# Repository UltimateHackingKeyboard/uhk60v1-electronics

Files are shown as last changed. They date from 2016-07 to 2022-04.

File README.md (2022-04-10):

Ultimate Hacking Keyboard electronics
=====================================



Contained are the schematics and board layout KiCad files for the [Ultimate Hacking Keyboard](https://ultimatehackingkeyboard.com/).

Please make sure to clone this repo with:

`git clone --recursive https://github.com/UltimateHackingKeyboard/uhk60v1-electronics.git`

Now, you should be able to open any of the 4 [KiCad](https://kicad.org/) projects of the repo:

* [left-main](left-main) contains main PCB of left keyboard half.
* [right-main](right-main) contains the main PCB of the right keyboard half.
* [display](display) contains the PCB that interfaces our custom manufactured LED segment display with the left main PCB.
* [connectors](connectors) are very small PCBs that are soldered vertically to the left and right main circuit boards to interconnect the keyboard halves without needing a bridge cable.

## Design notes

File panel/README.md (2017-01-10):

# Panelization script

Run `generate-panel.sh` to create a `panel.kicad_pcb` file out of every boards of the UHK. Then you shall generate gerbers from `panel.kicad_pcb` and send them to the fab house of your choice.

Please note that `generate-panel.sh` merely places the boards next to each other based on static coordinate offsets and does not add routing, breakout tabs, or anything fancy. This may or may not work out for you.

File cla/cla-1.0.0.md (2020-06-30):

# Contributor Agreement
## Individual Contributor Exclusive License Agreement version 1.0.0

Thank you for your interest in contributing to Ultimate Gadget Laboratories Kft.'s Ultimate Hacking Keyboard electronics design ("We" or "Us").

The purpose of this contributor agreement ("Agreement") is to clarify and document the rights granted by contributors to Us.

By signing this Agreement, you agree that the following terms apply to all of your past, present and future contributions to the project.

## How to use this Contributor Agreement

If You are an employee and have created the Contribution as part of your employment, You need to have Your employer approve this Agreement or sign the Entity version of this document. If You do not own the Copyright in the entire work of authorship, any other author of the Contribution should also sign this – in any event, please contact Us at support@UltimateHackingKeyboard.com

## 1. Definitions

**"You"** means the individual Copyright owner who Submits a Contribution to Us.

**"Contribution"** means any original work of authorship, including any original modifications or additions to an existing work of authorship, Submitted by You to Us, in which You own the Copyright.

**"Copyright"** means all rights protecting works of authorship, including copyright, moral and neighboring rights, as appropriate, for the full term of their existence.

**"Material"** means the software or documentation made available by Us to third parties. When this Agreement covers more than one software project, the Material means the software or documentation to which the Contribution was Submitted. After You Submit the Contribution, it may be included in the Material.

**"Submit"** means any act by which a Contribution is transferred to Us by You by means of tangible or intangible media, including but not limited to electronic mailing lists, source code control systems, and issue tracking systems that are managed by, or on behalf of, Us, but excluding any transfer that is conspicuously marked or otherwise designated in writing by You as "Not a Contribution."

**"Documentation"** means any non-software portion of a Contribution.

## 2. License grant

### 2.1 Copyright license to Us

Subject to the terms and conditions of this Agreement, You hereby grant to Us a worldwide, royalty-free, exclusive, perpetual and irrevocable (except as stated in Section 8.2) license, with the right to transfer an unlimited number of non-exclusive licenses or to grant sublicenses to third parties, under the Copyright covering the Contribution to use the Contribution by all means, including, but not limited to:

* publish the Contribution,
* modify the Contribution,
* prepare derivative works based upon or containing the Contribution and/or to combine the Contribution with other Materials,
* reproduce the Contribution in original or modified form,
* distribute, to make the Contribution available to the public, display and publicly perform the Contribution in original or modified form.

### 2.2 Moral rights

Moral Rights remain unaffected to the extent they are recognized and not waivable by applicable law.

### 2.3 Copyright license back to You

Upon such grant of rights to Us, We immediately grant to You a worldwide, royalty-free, non-exclusive, perpetual and irrevocable license, with the right to transfer an unlimited number of non-exclusive licenses or to grant sublicenses to third parties, under the Copyright covering the Contribution to use the Contribution by all means, including, but not limited to:

* publish the Contribution,
* modify the Contribution,
* prepare derivative works based upon or containing the Contribution and/or to combine the Contribution with other Materials,
* reproduce the Contribution in original or modified form,
* distribute, to make the Contribution available to the public, display and publicly perform the Contribution in original or modified form.

This license back is limited to the Contribution and does not provide any rights to the Material.

## 3. Patents

### 3.1 Patent license

Subject to the terms and conditions of this Agreement You hereby grant to Us and to recipients of Materials distributed by Us a worldwide, royalty-free, non-exclusive, perpetual and irrevocable (except as stated in Section 3.2) patent license, with the right to transfer an unlimited number of non-exclusive licenses or to grant sublicenses to third parties, to make, have made, use, sell, offer for sale, import and otherwise transfer the Contribution and the Contribution in combination with any Material (and portions of such combination). This license applies to all patents owned or controlled by You, whether already acquired or hereafter acquired, that would be infringed by making, having made, using, selling, offering for sale, importing or otherwise transferring of Your Contribution(s) alone or by combination of Your Contribution(s) with any Material.

### 3.2 Revocation of patent license

You reserve the right to revoke the patent license stated in section 3.1 if We make any infringement claim that is targeted at your Contribution and not asserted for a Defensive Purpose. An assertion of claims of the Patents shall be considered for a "Defensive Purpose" if the claims are asserted against an entity that has filed, maintained, threatened, or voluntarily participated in a patent infringement lawsuit against Us or any of Our licensees.

## 4. Disclaimer

THE CONTRIBUTION IS PROVIDED "AS IS". MORE PARTICULARLY, ALL EXPRESS OR IMPLIED WARRANTIES INCLUDING, WITHOUT LIMITATION, ANY IMPLIED WARRANTY OF SATISFACTORY QUALITY, FITNESS FOR A PARTICULAR PURPOSE AND NON-INFRINGEMENT ARE EXPRESSLY DISCLAIMED BY YOU TO US AND BY US TO YOU. TO THE EXTENT THAT ANY SUCH WARRANTIES CANNOT BE DISCLAIMED, SUCH WARRANTY IS LIMITED IN DURATION AND EXTENT TO THE MINIMUM PERIOD AND EXTENT PERMITTED BY LAW.

## 5. Consequential damage waiver

TO THE MAXIMUM EXTENT PERMITTED BY APPLICABLE LAW, IN NO EVENT WILL YOU OR WE BE LIABLE FOR ANY LOSS OF PROFITS, LOSS OF ANTICIPATED SAVINGS, LOSS OF DATA, INDIRECT, SPECIAL, INCIDENTAL, CONSEQUENTIAL AND EXEMPLARY DAMAGES ARISING OUT OF THIS AGREEMENT REGARDLESS OF THE LEGAL OR EQUITABLE THEORY (CONTRACT, TORT OR OTHERWISE) UPON WHICH THE CLAIM IS BASED.

## 6. Approximation of disclaimer and damage waiver

IF THE DISCLAIMER AND DAMAGE WAIVER MENTIONED IN SECTION 4. AND SECTION 5. CANNOT BE GIVEN LEGAL EFFECT UNDER APPLICABLE LOCAL LAW, REVIEWING COURTS SHALL APPLY LOCAL LAW THAT MOST CLOSELY APPROXIMATES AN ABSOLUTE WAIVER OF ALL CIVIL OR CONTRACTUAL LIABILITY IN CONNECTION WITH THE CONTRIBUTION.

## 7. Term

7.1 This Agreement shall come into effect upon Your acceptance of the terms and conditions.

7.2 In the event of a termination of this Agreement Sections 4, 5, 6, 7 and 8 shall survive such termination and shall remain in full force thereafter. For the avoidance of doubt, (sub)licenses that have already been granted for Contributions at the date of the termination shall remain in full force after the termination of this Agreement.

## 8. Miscellaneous

8.1 This Agreement and all disputes, claims, actions, suits or other proceedings arising out of this agreement or relating in any way to it shall be governed by the laws of Hungary excluding its private international law provisions.

8.2 This Agreement sets out the entire agreement between You and Us for Your Contributions to Us and overrides all other agreements or understandings.

8.3 In case of Your death, this agreement shall continue with Your heirs. In case of more than one heir, all heirs must exercise their rights through a commonly authorized person.

8.4 If any provision of this Agreement is found void and unenforceable, such provision will be replaced to the extent possible with a provision that comes closest to the meaning of the original provision and that is enforceable. The terms and conditions set forth in this Agreement shall apply notwithstanding any failure of essential purpose of this Agreement or any limited remedy to the maximum extent possible under law.

8.5 You agree to notify Us of any facts or circumstances of which you become aware that would make this Agreement inaccurate in any respect.

## 9. Signatures

I have read this Agreement, and fully agree to it by signing it with my GitHub username:

- @ipanti
- @mondalaci
- @spuder

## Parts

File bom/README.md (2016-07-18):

# BOM generator

1. Invoke `npm install` to install the dependencies.
2. Generate report files which serve as the input of the script by opening the left-main, right-main, and display board in pcbnew and clicking on File > Fabrication Outputs > Footprint (.rpt) Report.
3. Execute `bom-generator.js`

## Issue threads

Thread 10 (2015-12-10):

Re-wrap and reposition the "Unscrew the 5 large below the keycaps..."

spuder, 2015-12-10:
Re-wrap and reposition the "Unscrew the 5 large below the keycaps and the 1 screw on the PCB" text to be more readable.

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

spuder, 2015-12-10:
@mondalaci Could I get some feedback on what you are looking for here?

Here is one proposal that rephrases for less characters and moves text a little further away from the vias / holes.

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

mondalaci, 2015-12-10:
@spuder Your suggested solution looks great! I'd love to merge a pull request implementing the above.

Closed 2016-01-05.

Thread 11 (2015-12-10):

Move the parts farther from the pins of the MX switches which are too close

spuder, 2015-12-10:

mondalaci, 2016-09-27:
I'll do this along with a number of other related changes. Now we know the exact specs for selective reflow soldering.

Closed 2016-09-27.

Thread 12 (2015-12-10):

Use larger pitch components?

spuder, 2015-12-10:
Look into the possiblity of using larger pitch components so that we could could make our manufacturing tolerances less strict resulting in lower prices and increased yield

mondalaci, 2016-09-27:
Now we use the largest pitch components possible.

Closed 2016-09-27.

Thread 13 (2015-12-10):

Add fixating pins to the Cherry MX module

spuder, 2015-12-10:
Add fixating pins to the Cherry MX module so that PCB mounted switches can be used, too

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

There are two libraries that already have this

https://github.com/geekhack-org/kicad-library

https://github.com/c0z3n/cherrymx-eagle

The latter would need to be converted to kicad. (done)

- [x] Ensure license is compatible with the UHK https://github.com/geekhack-org/kicad-library/issues/1
- [x] Get cherry mx library https://github.com/UltimateHackingKeyboard/ugl-kicad-libs/pull/2

mondalaci, 2016-09-27:
Done.

Closed 2016-09-27.

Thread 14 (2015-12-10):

Add pins for Matias switches if possible

spuder, 2015-12-10:
Not impossible, but difficult
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

mondalaci, 2015-12-13:
I've seen two examples of implementing this. I assume that the double hole version probably works better, but maybe we should ask Matias.

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

spuder, 2016-01-04:
I've contacted Matias support a couple of times with no response, asking if they have cad files. I haven't been able to find any github projects that contains a matias libraries, though this one looks promising.

https://github.com/kiibohd/pcb/tree/master/ICED%20-%20Right/prettylib

spuder, 2016-01-05:
Matias switch cad files can be downloaded from here:

http://matias.ca/switches/Matias_Switch_3D.zip

They are in the format .EPRT .IGS and .STEP They will need to be converted to a .kicad_mod file

Here are the blueprints:

Quiet Click
http://matias.ca/switches/quiet/blueprints/?p=4

Click
http://matias.ca/switches/click/blueprints/?p=1

Quiet Linear
http://matias.ca/switches/linear/blueprints/?p=1

mondalaci, 2016-01-05:
Great job! Looks like all of the above information is indirectly accessible via http://matias.ca/switches/

Just emailed Matias and asked them about the suggested universal switch footprint along with some further info.

spuder, 2016-01-07:
I spent some time creating a custom part from the blueprints, only to later find that the buttons library included in kicad already includes a matias part!

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

spuder, 2016-01-12:
This has been completed for the left hand side.
https://github.com/spuder/electronics/tree/feature/%2313_matias
 It has the following considerations that need to be reviewed

- 4 new vias near iso switches are different from the via part that is in the ugl library. I don't see a way to change the built in via into a ugl:via

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
- Switch 27 has a hole that goes off the end of the board. Will that cause a problem?

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

The following are items that shouldn't cause problems, but should be closely inspected

- verify that there is enough space for the vertical capacitor

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

- verify the new layout of capacitors has enough room

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

Lastly, because of the new switch layout that includes the stabilizing holes for the cherry mx boards, there is a DRC that fails. There is no way around this. We could:
1. Allow the DRC to fail for the overlapping pads
2. Create a new custom part that includes strangely shaped holes

Neither solution is ideal. There has been some discussion in the kicad forms on how to handle this situation.

https://forum.kicad.info/t/multiple-pin-components/2006

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

spuder, 2016-01-13:
I spoke with matias. They don't offer any sample kits, but they will sell me 3 keys (one of each type) for $10. Otherwise we would need to buy a 200 key set for $50 (plus another $50 for the keycaps).

http://matias.ca/order/#switches

mondalaci, 2016-01-13:
Sorry for the late reply, these have been busy days.

The most important thing is that the Cherry switches should probably be reversed for optimized backlighting. The reason is that unlike most keyboards the UHK makes heavy use of the front side of the keycaps for featuring the labels of the Mod layer. Because of this, the front labels should be lit. This needs the LEDs to be featured on the user-facing sides of the switches, not the other way.

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

Above is the KBT Pure 60% keyboard to illustrate my point.

In light (no pun intended) of the above, what route would you take, Spencer? I'd rather vote for reversing the switches which would negate some or all of your work. I'd hate to do that but I think it'd make sense to future-proof the design in this respect.

Please let me answer your other questions too a little bit later.

spuder, 2016-01-14:
I agree reversing the part would be best. Doing so would be a very big change and I don't know how soon the board is to being finalized and delivered. I won't be sad if we don't use the work I've done so far because it has been a learning experience. I've used eagle, but never kicad.

Two approaches

## Iterative
Keep working on the board in phases. Ship the version that is ready at the final date.

6.0 => matias + cherry mx stabilizer
7.0 => reversed switches
8.0 => led lights (with reversed switches).

## Incremental
Overhaul board to have all the desired features

reversed switches + matias + cherry mx stabilizer + led lights

---
It all comes down to timing. I estimate the latter would require changing over 30% of the board layout, and would take several months plus new prototypes. If you think there is time, I'm willing to help either way.

spuder, 2016-01-14:
@mondalaci I've been thinking about this more.

I'm ok to throw away the work that I've done on the matias switches, though I think it still might be useful because while adding the cherry mx stabilizer holes, I've moved traces and components out of the way. Rotating the part 180 degrees will reuse those holes.

Here is what I think is the best course of action

To the master branch:
- Add the new pogo plugs
- Swap the atmega for the teensy
- Add the 4P4C

Then try and merge my matias branch. If the merge works, we just need to rotate the components. If the merge doesn't work, then I'm ok to start over. I'm much faster at kicad now.

I suspect this would take a few weeks. Once that is done:

If sufficient time, add the led circuitry
If approaching deadline, skip the leds and get a prototype made.

Thoughts?

spuder, 2016-01-15:
There is a major obstacle to rotating the keycaps around

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

switch 13 might need to be rotated 90 degrees, or left upside down not sure if that would make the led lighting look weird.

mondalaci, 2016-01-15:
This one shouldn't be a problem. Just talked to Andras and he said that the FFC connector can be moved a little farther away from SW13. Relative to SW13 the new position of the FFC connector should be x-4.364mm and y-11.257mm.

mondalaci, 2016-01-15:
Thanks for elaborating on the two approaches, good thinking! I'd rather prefer your incremental approach (reversed switches + matias + cherry mx stabilizer + led lights).

But before executing this complex change it'd be worth to wait for Andras to overhaul the soft keepout areas and slighly tweak the shape of the PCB based on the updated CAD data. He should be ready on the upcoming week, and after that this sweeping change could take place.

At this point I'm only unsure about how to implement LED backlighting for Matias switches. Unlike for Cherry switches this is rather nontrivial but the above overhaul shouldn't be affected by adding Matias LEDs later on.

mondalaci, 2016-01-15:
Regarding the overlapping stabilizer pins of the Cherry switches I think the best solution is to create two additional hybrid footprints that are the same as the hybrid footprint except without left / right stabilizer pins. We could use one of these modified footprints wherever necessary.

mondalaci, 2016-01-15:
Thanks for looking into Matias keycaps, Spencer! I'm not terribly worried about them right now. I'm rather concerned about future-proofing the PCB to make it compatible with Matias switches. We should be able to scavenge most (if not all) of the Matias keycaps from existing Matias/ALPS keyboards that can be purchased from eBay for example.

spuder, 2016-01-18:
For reference, the ergodox infinity was recently updated to support all major keycaps

https://www.massdrop.com/buy/infinity-ergodox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(Active

- Cherry
- Matias
- Gateron
- Zealios

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

It also has usb3 support

mondalaci, 2016-01-18:
Good find!

I can't see how Gateron differs from Cherry. I think Gateron simply has a single version featuring fixation pins. Is Zealios different from the Cherry? I don't think so. It's nice that Matias is supported but elongated holes might be problematic for soldering purposes.

mondalaci, 2016-01-18:
Please let me answer the rest of your questions, Spencer.

It shouldn't be a problem that switch 27 has a hole that goes off the end of the board. Worst case scenario: the stabilizer pin in question will be cut off. But Andras will try to make space for the stabilizer pin in the case.

The vias in question can't be changed to ugl:via because these vias aren't separate modules. You can simply choose the desired via from the via combobox that is located rightwards of the track width combobox below the top menu and then right-click on the via, select it from the pop-up menu, then click on the Change Via Size and Drill menu item.

I think there should be enough space for the vertical capacitor.

When you said "verify the new layout of capacitors has enough room" did you mean resistors? I assume you meant the R22 and its close friends. We'll end up using a resistor network instead of the individual resistors so as long as the DRC is ok the current layout it should be fine.

spuder, 2016-01-21:
For reference, it looks like the corsair k70 uses upside down cherry mx leds. The keycaps also have the transparent letters near the top

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

mondalaci, 2016-01-21:
Almost every keyboard on the market uses upside LEDs. Downside LEDs only make sense when the letters are not only top-printed but side-printed, too.

spuder, 2016-01-25:
@mondalaci I see you added a git submodule for the kibohd footprints.

I've looked into using their footprint instead of the one I made.

https://github.com/kiibohd/pcb/issues/3

Thoughts on using their footprint?

Pros:

- Tested

Cons:

- Matias switch holes are slightly different from matias blueprints
- Can PCB manufacture drill oblong shaped holes?
- Is CERN license compatible with UHK license?
- PCB will 'look' kind of like the ergodox with the oblong holes

If you don't have a problem with these, then I suggest we just use their footprint instead of the one I made.

mondalaci, 2016-01-25:
@spuder I'd prefer to use your version mainly because it should be easier to solder due to the circular drill holes. I've only added the kiibohd repo because it may be worth to use their Kinetis processor module.

I didn't think that license incompatibility may be an isssue. The way I though about it is that these are two separate projects. Would it be problematic to use a CERN-licensed component in a GPL-licensed project?

mondalaci, 2016-09-27:
Done.

Closed 2016-09-27.

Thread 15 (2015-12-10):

Cherry MX LED lights

spuder, 2015-12-10:
Allow modders to use cherry mx switches with LEDs

- [x] Update library to use cherry mx pinout with led holes. [example](http://cherrycorp.com/wp-content/uploads/2014/12/11.gif)   done: https://github.com/UltimateHackingKeyboard/ugl-kicad-libs/pull/2
- [ ] Choose a led driver that handles PWM
- [ ] Determine if sufficient pins available on the AtMega for led driver
- [ ] Design charlieplexing matrix

Optional features

- [ ] Software defined brightness, [like code keyboard https://codekeyboards.com/])
- [ ] Individually toggle buttons (caps lock, num lock)

Related https://github.com/UltimateHackingKeyboard/electronics/issues/13

mondalaci, 2016-01-05:
It'd be useful to take a look at some open source keyboard designs that have backlighting. I'd rather go for a simple implementation that supports a single PWM channel for all the LEDs. So I mean no per-LED backlighting.

spuder, 2016-01-18:
Some possible led drivers

[74HC595 Shift Register](https://www.adafruit.com/products/450)
- only needs 3 pins (SPI)
- can daisy chain
- Have to do charlie plexing in software

[MAX7219 Led Driver](https://www.adafruit.com/products/453)
- Handles control and refreshing. Greatly simplifies code
- Kind of expensive.

I'm leaning towards the first option because it is cheaper.

The teensy has an spi library https://www.pjrc.com/teensy/td_libs_SPI.html

mondalaci, 2016-01-19:
I'm aware of these options. Unfortunately, the 74HC595 only allows for a single LED per pin and the MAX7219 is fabulously expensive.

I've been suggested the TPS61193 lately which may work for us. We could string about a dozen of LEDs per OUTx pin.

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

I personally don't feel confident in my abilities to choose the best part for this purpose and will surely talk to an electronics engineer before making a choice. But suggestions are always welcome!

spuder, 2016-01-19:
Looking at the [ergodox infinity](https://github.com/kiibohd/pcb/tree/master/ICED%20-%20Left), they are using the  [IS31FL3731C](http://www.mouser.com/ProductDetail/ISSI/IS31FL3731C-SALS2/?qs=rnuWwpjhhVvfjmOe6D9bPQ%3D%3D)

mondalaci, 2016-01-19:
Yes, I know, but [nobody has it on stock](https://octopart.com/search?q=IS31FL3731C) which is not very promising.

mondalaci, 2016-02-09:
Apparently, this IC is [actually available](https://octopart.com/search?q=IS31FL3731) without the closing C in its part name.

mondalaci, 2016-09-27:
Done. We went with the IS31FL3731-SALS2.

Closed 2016-09-27.

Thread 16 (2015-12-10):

USB type C connector?

spuder, 2015-12-10:
Look into the possibility of using a USB type C connector

mondalaci, 2016-01-04:
András has looked into the possibility of using USB type-C and concluded that it doesn't fit into the case given its larger size. We'll stick to USB Mini-B. I think it's the best choice given its small size and robust design.

Closed 2016-01-04.

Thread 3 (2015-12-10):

Replace 6P4C connectors with 4P4C

spuder, 2015-12-10:
Replace 6P4C connectors with 4P4C. Make sure that the chosen connector and the wall of the case leaves enough space for the clip so that it can be pressed. Also, 4P4C probably almost always uses reverse wiring!

mondalaci, 2015-12-13:
@spuder Thanks for confirming reverse wiring! I meant to use reverse wiring for 4P4C instead of the current straight wiring because according to my experience telephone cord cables use reverse wiring.

I'd love to back up the prevalence of reverse wiring with facts beyond my (very limited experience) but couldn't find any stats of the percentage of telephone cords with straight vs reverse wiring. The type of wiring shouldn't matter for telephones but it does matter for the UHK.

Andras always does mechanical interference checks in CAD so that shouldn't be an issue.

spuder, 2015-12-13:
Sorry, I can't confirm the reverse wiring as I don't know anything about that part. The comment was copied and pasted directly from the TODO

>-* Replace 6P4C connectors with 4P4C. Make sure that the chosen connector and the wall of the case leaves enough space for the clip so that it can be pressed. Also, 4P4C probably almost always uses reverse wiring!

https://github.com/UltimateHackingKeyboard/electronics/commit/c4327e8296f0e911c573165dafe6d01c02b7f867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

mondalaci, 2015-12-13:
So I commented my own comment - that's hilarious! :)

Sorry, it's my bad, and will look into it another time.

mondalaci, 2016-09-27:
Done.

Closed 2016-09-27.

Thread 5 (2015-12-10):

Replace the spring connector with a vertical PCB that uses pogo pins

spuder, 2015-12-10:

mondalaci, 2016-09-27:
Done.

Closed 2016-09-27.

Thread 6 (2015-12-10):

Reduce resistor values on the TX and RX lines

spuder, 2015-12-10:
Reduce resistor values on the TX and RX lines of the board-to-board connectors because they didn't work on the 5.1 generation prototypes

spuder, 2015-12-13:
R7 => 10K
R8 => 10K
R9 => 100K
R10 => 10K

What values should these be?

mondalaci, 2015-12-13:
Great question! I'm fairly clueless about analog electronics so a professional electronics engineer will revise the design before manufacturing and fix such issues.

In any case, I should add detailed instructions about using the UGL and Opendous KiCad libraries because they're not added by default, which can be seen on the attached picture.

spuder, 2015-12-13:
I was just asking about those libraries in #22

mondalaci, 2016-09-27:
This has been redesigned.

Closed 2016-09-27.

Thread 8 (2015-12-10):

Move via farther from the pad of CR6 on the left main PCB

spuder, 2015-12-10:
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

mondalaci, 2016-09-27:
Not relevant anymore. Individual ESD suppressors have been replaced with ESD suppressor arrays. These kinds of issues will be resolved regardless.

Closed 2016-09-27.

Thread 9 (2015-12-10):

Redesign the pads of the vertical PCB to not interfere with the keycap stabilizer

spuder, 2015-12-10:
Redesign the pads of the vertical PCB to not interfere with the keycap stabilizer. Mechanical solder pads should only be added at the edges and the middle pads should be reduced

mondalaci, 2016-09-27:
Done.

Closed 2016-09-27.

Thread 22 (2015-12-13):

Where do you get the libraries from?

spuder, 2015-12-13:
I know you are really busy, so I'll try and be as self sufficient as possible.

I'm updating the readme with instructions so others can easily contribute. There are 3 libraries required

- special
- opendous
- uhk libs

I've figured out how to install opendous and the uhk libs, but even after a couple hours of searching, I can't find the 'special' library

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

Do you know where that library is located? Once I find it I'll document it so others can find it.

mondalaci, 2015-12-13:
* The "uhk libs" library can be found at https://github.com/UltimateHackingKeyboard/ugl-kicad-libs
* I think this is the relevant Opendous library but please let me know if it doesn't work: https://code.google.com/p/opendous/downloads/detail?name=KiCad_Libraries-2012-10-18.zip&can=2&q=
* I'm not sure about the special library. The "kicad special library" google search yielded https://forum.kicad.info/t/the-following-libraries-were-not-found-special-solved/870 which might be a KiCad bug. Could you please look into it some more?

Thank you so much!

Closed 2015-12-14.

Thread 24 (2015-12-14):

Create automated system to compare kicad diffs

spuder, 2015-12-14:
When a new merge request is made. Use travis-ci to generate gerbers/pdf/png files and then use `linux compare` to generate a visual diff.

http://www.evilmadscientist.com/2011/improving-open-source-hardware-visual-diffs/

https://github.com/blairbonnett-mirrors/kicad/blob/master/demos/python_scripts_examples/plot_board.py

- [x] Create travis config file
- [x] Create scripts to generate diffs based off of plot_board.py
- [x] Create aws account to upload artifacts to s3

You can assign this to me as I'm currently working on it.

mondalaci, 2015-12-14:
Awesome thought of automating this!

Just made you a collaborator of this repo with write access, and assigned this issue to you.
Please let's not change the board files until the visual diff mechanism is in place. I'm very afraid of the board changes as I can't see them and they may result in broken boards which translate to huge problems / losses upon manufacturing the PCB.

Sorry for the delay regarding the other issues, I'll catch up later on.

Thank you so much!

spuder, 2015-12-14:
Awesome thanks.
I understand that you have plenty of other things to worry about right now.
I have some manual diffs ready now, but I'm ok waiting to merge them until we have a more polished diff system in place.

spuder, 2015-12-16:
I have a working implementation in this branch in my fork

https://github.com/spuder/electronics/tree/feature/wip_travis

It still has the following issues:

- Granting public access to the s3
- Minor updates to the diffs
- Decide if travis should generate gerbers too

timofonic, 2015-12-19:
Are there a possibility of making this KiCad native? It would be a great addition for KiCad users!

It would be great if someone implements Git support into KiCad, then auto-generate visual-diffs...

I would like to "hack" your schematics. Your project seems interesting and I would like to donate something, but I'm unable to spend so much money so maybe I can contribute in possible hardware updates or forks :dancer:

spuder, 2015-12-19:
Stand by, i'll be pushing a script soon that uses vagrant and the kicad python api to make images showing diffs. Its as native as can be right now

spuder, 2015-12-21:
I have opened merge request #27 It has a fairly polished collection of scripts that when run generate 14 pdf files, converts them to .png files, and then runs `compare` to show the changes

    ./scripts/generate-png-diff.sh

The script that generates the plots is located externally here:

https://gist.github.com/spuder/4a76e42f058ef7b467d9

It still could use some minor improvements, but it is good enough to see at a glance exactly what was changed.

It also has a travis config file, that runs these scripts.

Here is what happens if nothing has changed:

https://travis-ci.org/spuder/electronics/builds/98057604

Here is what it looks like when a change is made to a file ending in .kicad_pcb

https://travis-ci.org/spuder/electronics/builds/97929762

There are still two remaining tasks

- Automatically upload the .png artifacts to amazon s3 or imgur.com on commit
- Have travis-ci post a link to the generated files inside the comments section of github.

I'll keep working on those, but I want to merge what I have now so that people can use these scripts without waiting.

Here are some samples of what happens when the kicad_file is edited. Here I intentionally moved the rj11 connector:

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

mondalaci, 2015-12-21:
I'm absolutely thrilled about this, thank you so much @spuder! Let me merge the relevant pull request real quick.

mondalaci, 2015-12-21:
@timofonic Sure thing, everybody's welcome to hack the schematic! Let me know if you need any help.

spuder, 2015-12-23:
Marking as done.
Having travis upload the .png files to imgur and automatically posting links in the github comments wont have much use, since travis secrets are not persisted across forks. I won't automate that unless I there is a real need, and I figure out a way that works with forks.

I'll update the README instructing users to upload their diffs manually.

mondalaci, 2015-12-27:
@spuder Thank you for your hard work, this looks excellent the way it is! The rest is only icing on the cake and certainly not urgent.

hoijui, 2020-09-09:
As an alternative, you might want to have a look at the very powerful [KiBot](https://github.com/INTI-CMNB/KiBot) tool.

Closed 2015-12-23.

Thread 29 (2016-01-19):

Parts need unique names to allow for auto routing

spuder, 2016-01-19:
If you attempt to run the auto router, you will get the following errors

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

The first is caused because the holes do not have unique values

The latter is because every via has the same value

mondalaci, 2016-01-19:
I wasn't aware of this issue but I'm not concerned about it because the autorouter is practically useless for complicated designs like the UHK.

I rather wouldn't care about these issues because it would require us to individually name the reference designators of holes and vias which would result in increased mainteance burden on the long run for no real benefit.

Closed 2016-01-19.

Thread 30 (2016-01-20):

Want to add the opensource logo to the board?

spuder, 2016-01-20:
Thoughts on adding the official open source logo to the silkscreen of pcb?

http://www.oshwa.org/definition/

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

https://www.youtube.com/watch?v=QrHoowPpdQ8

mondalaci, 2016-01-20:
Correct me if I'm wrong but I think the UHK is not fully open according to OSH principles because we haven't yet released the CAD files.

spuder, 2016-01-20:
Good point, didn't think of that.

I've read it a few times, and I see how it could be argued both ways. As a whole, the keyboard doesn't meet the criteria yet. The pcb most likely does. I don't know if the enclosure counts.

>The program must include source code, and must allow distribution in source code as well as compiled form. Where some form of a product is not distributed with source code, there must be a well-publicized means of obtaining the source code for no more than a reasonable reproduction cost preferably, downloading via the Internet without charge.

I'll check with the mailing list to get clarification on this principle. I don't think I'll pursue this much further.

Closed 2016-01-20.

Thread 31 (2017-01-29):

Replace 5 pin TVS array footprints with 6 pin footprints

mondalaci, 2017-01-29:
6 pin TVS arrays (SC-74, SOT-223-6, 6-TSSOP) are much more prevalent than 5 pin TVS arrays (SC-74A, SOT-223-5), and they're backwards compatible with 5 pin footprints, so this will enable us to choose a wider variety of parts.

mondalaci, 2017-01-31:
I left a DRC error but I don't care because it's not critical, and the right board is about to be redesigned very soon.

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

Closed 2017-01-31.

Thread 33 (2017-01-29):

Reverse 4P4C connector pins

mondalaci, 2017-01-29:
Currently, the wiring of the bridge cable is backwards, so we should reverse the wiring of either the left or right 4P4C connector.

Closed 2017-02-18.

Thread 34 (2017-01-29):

Create 4 layer versions of the left and right PCBs

mondalaci, 2017-01-29:
Hopefully, #32 will resolve the EMC issues, and we'll pass the next EMC test with flying colors, but we can't be sure. At this point, we want to put the UHK to market as soon as possible, so as a safety measure, we will design 4 layer versions of the left and right PCBs. On the upcoming EMC test, we'll give a whirl to both versions and pick the 4 layer version if necessary.

After finalizing the left and right boards, the `left-main` directory should be copied as `left-main-4-layers` and `right-main` as `right-main-4-layers`, then the 4 layer versions should be redesigned accordingly. The middle layers should exclusively contain GND and VCC.

mondalaci, 2017-02-27:
This has been done.

Closed 2017-02-27.

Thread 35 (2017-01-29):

Protect against reverse polarity bridge cables

mondalaci, 2017-01-29:
Creating custom bridge cables is a possibility, and it's easy to overlook the wiring resulting in reverse-wired bridge cables that can damage the electronics. In order to avoid possible damages, we'll implement reverse voltage protection using the following schematic:

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

The above circuit should be added right between FB1 and C6 according to the following schematic:

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

Closed 2017-01-30.

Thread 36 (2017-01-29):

Add more vias to the female connector board

mondalaci, 2017-01-29:
Currently, there is only one via per pad on the female connector board. We should use more, especially for VCC and GND.

Closed 2017-01-29.

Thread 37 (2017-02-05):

Change MKL03Z8VFK4 to MKL03Z32VFK4

mondalaci, 2017-02-05:
We'll be using the MKL03Z32VFK4 MCU instead of the current MKL03Z8VFK4. It's the exact same MCU in every respect but it has 32K flash instead of 8K. A new schematic part should be cloned from the old MCU accordingly, so its name would reflect the name of the new MCU. The new schematic part will have to be added to the ugl-kicad-lib repo.

Closed 2017-04-16.

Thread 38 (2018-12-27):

Travis script throwing error

zen, 2018-12-27:
I'm trying to use the travis diff script and it's throwing error:
root@12ba8a8b9dbe:/kicad# ./generate-png-diff.sh
Copying 187bd8e:drone-kicad-sample.kicad_pcb to ./plot/187bd8e/
Kicad files saved to:  './plot/current' and './plot/187bd8e'
Converting ./plot/current/drone-kicad-sample.kicad_pcb to .pdf:  Files will be saved to /tmp/pdf
Traceback (most recent call last):
  File "/tmp/plot_board.py", line 172, in <module>
    popt.SetColor(YELLOW)
NameError: name 'YELLOW' is not defined
Converting ./plot/187bd8e/drone-kicad-sample.kicad_pcb to .pdf's Files will be saved to /tmp/pdf
Traceback (most recent call last):
  File "/tmp/plot_board.py", line 172, in <module>
    popt.SetColor(YELLOW)
NameError: name 'YELLOW' is not defined

zen, 2018-12-27:
@spuder probably something for you to take a look.

spuder, 2018-12-27:
Most likely what is going on is an incompatible version of a package that is installed. The travis scripts are only tested on ubuntu 14.04 (trusty).

Are you running these scripts on your workstation? Or is it travis that is failing?

Do you have docker installed? Could you try running these commands and see if it gives the same error?

```
docker run -it --rm -v $(pwd):/data ubuntu:xenial /bin/bash
apt-get update
apt-get install -y sudo software-properties-common
cd /data
./scripts/1-add-repos.sh
./scripts/2-install-dependencies.sh
./scripts/generate-png-diff.sh
```

zen, 2018-12-28:
Hi, thanks.
With manual steps it's even worse:
`root@f9e6f20d857e:/data# ./scripts/generate-png-diff.sh
Copying 187bd8e:drone-kicad-sample.kicad_pcb to ./plot/187bd8e/
Kicad files saved to:  './plot/current' and './plot/187bd8e'
Converting ./plot/current/drone-kicad-sample.kicad_pcb to .pdf:  Files will be saved to /tmp/pdf
14:10:10: Debug: Skipping general section token 'drawings'
14:10:10: Debug: Skipping general section token 'tracks'
14:10:10: Debug: Skipping general section token 'zones'
14:10:10: Debug: Skipping general section token 'symbol'
Traceback (most recent call last):
  File "/tmp/plot_board.py", line 58, in <module>
    board = LoadBoard(filename)
  File "/usr/lib/python2.7/dist-packages/pcbnew.py", line 12870, in LoadBoard
    return _pcbnew.LoadBoard(*args)
IOError: KiCad was unable to open this file, as it was created with a more recent version than the one you are running. To open it, you'll need to upgrade KiCad to a more recent version.

Date of KiCad version required (or newer): 11/30/17

Full error text:
KiCad was unable to open this file, as it was created with a more recent version than the one you are running. To open it, you'll need to upgrade KiCad to a more recent version.

Date of KiCad version required (or newer): 11/30/17

Full error text:
PARSE_ERROR: Expecting 'circle, rectangle, oval, or trapezoid' in input/source
'./plot/current/drone-kicad-sample.kicad_pcb'
line 172
offset 16
from dsnlexer.cpp : Expecting() : line 369

Converting ./plot/187bd8e/drone-kicad-sample.kicad_pcb to .pdf's Files will be saved to /tmp/pdf
14:10:10: Debug: Skipping general section token 'drawings'
14:10:10: Debug: Skipping general section token 'tracks'
14:10:10: Debug: Skipping general section token 'zones'
14:10:10: Debug: Skipping general section token 'symbol'
Traceback (most recent call last):
  File "/tmp/plot_board.py", line 58, in <module>
    board = LoadBoard(filename)
  File "/usr/lib/python2.7/dist-packages/pcbnew.py", line 12870, in LoadBoard
    return _pcbnew.LoadBoard(*args)
IOError: KiCad was unable to open this file, as it was created with a more recent version than the one you are running. To open it, you'll need to upgrade KiCad to a more recent version.

Date of KiCad version required (or newer): 11/30/17

Full error text:
KiCad was unable to open this file, as it was created with a more recent version than the one you are running. To open it, you'll need to upgrade KiCad to a more recent version.

Date of KiCad version required (or newer): 11/30/17

Full error text:
PARSE_ERROR: Expecting 'circle, rectangle, oval, or trapezoid' in input/source
'./plot/187bd8e/drone-kicad-sample.kicad_pcb'
line 171
offset 16
from dsnlexer.cpp : Expecting() : line 369

Converting /tmp/pdf/current/*.pdf to .png
I/O Error: Couldn't open file '/tmp/pdf/current/*.pdf': No such file or directory.
Converting /tmp/pdf/187bd8e/*.pdf to .png
I/O Error: Couldn't open file '/tmp/pdf/187bd8e/*.pdf': No such file or directory.
Generating composite image ./plot/diff-current-187bd8e/drone-kicad-sample-AssyOutlinesTop-1.png
Generating composite image ./plot/diff-current-187bd8e/drone-kicad-sample-AssyTop-1.png
Generating composite image ./plot/diff-current-187bd8e/drone-kicad-sample-CuBottom-1.png
Generating composite image ./plot/diff-current-187bd8e/drone-kicad-sample-CuTop-1.png
Generating composite image ./plot/diff-current-187bd8e/drone-kicad-sample-EdgeCuts-1.png
Generating composite image ./plot/diff-current-187bd8e/drone-kicad-sample-Layout-1.png
Generating composite image ./plot/diff-current-187bd8e/drone-kicad-sample-MaskBottom-1.png
Generating composite image ./plot/diff-current-187bd8e/drone-kicad-sample-MaskTop-1.png
Generating composite image ./plot/diff-current-187bd8e/drone-kicad-sample-PasteBottom-1.png
Generating composite image ./plot/diff-current-187bd8e/drone-kicad-sample-PasteTop-1.png
Generating composite image ./plot/diff-current-187bd8e/drone-kicad-sample-Silk-1.png
Generating composite image ./plot/diff-current-187bd8e/drone-kicad-sample-SilkBottom-1.png
Generating composite image ./plot/diff-current-187bd8e/drone-kicad-sample-SilkTop-1.png`

I cannot use 14.04 due to very old KiCAD package. I checked KiCAD source and cannot find where YELLOW and other colors are defined. It's very strange that other literals work and only YELLOW is missing
I think i might just change it to some other color.

By the way, are you going to maintain this script? Maybe it's worth separate repo?

spuder, 2019-01-04:
Still looking into this. The original purpose was to allow the UHK developers to visually see any changes made to the design in merge requests. It needs to be part of this repo so Travis-CI could run the script.

The root cause is that the designs have moved to kicad5, whereas the scripts were written for kicad4.

mondalaci, 2019-01-04:
We don't need the visual diff feature anymore, so feel free to remove it @spuder. Thanks for your help!

Closed 2019-06-20.

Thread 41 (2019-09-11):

USB line impedance seems to be really bad

dpiegdon, 2019-09-11:
In the PCB production version the USB signals are of *very* low quality. That probably explains some of the USB issues I have seen over the last months using my two UHKs.

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

In this capture, a reference signal (orange) is compared to the UHKs signal (yellow). An impedance mismatch is obvious. The signal corresponds to a UHK keyboard with stock USB cable connected to a USB port with an immediate transceiver. When connecting other devices to this setup, the signal looks almost like the reference.

I have a few suggestions for the next PCB revision (if there will be one, which I really hope):

* check USB design guidelines and trace impedance, esp. for any specifics for the microcontroller used. ( https://www.nxp.com/docs/en/supporting-information/Universal-Serial-Bus-Training.pdf )
* avoid layer hops whereever possible. at first glance, it seems feasible to move C13, R3 and D14 to the top layer and reroute the USB trace along their old position. that would reduce via-count by two per trace.
* avoid dangling traces. currently there are traces going from the USB port J1 north to the board edge. these are probably for electrical testing, QA and firmware flashing? maybe for these two a simple bed of nails and two in-line testbeds can be used? -- I just tested cutting off these traces, without any visible impact. so that probably is not not neccessary at 12MHz.

I know that these recommendations are coming very late and that you very likely already know about these issues and have thought about how to fix those, if ever. But I was missing any reference on the USB issues I have seen and thought that there should be at least a ticket on this.

Just for completeness, here are a few things I have seen over the last month:

* Linux: plenty of bursts of "hid-generic 0003:051D:0002.0006: control queue full" in dmesg. those come all day long. (thats probably a software/firmware bug, but I am not sure)
* when booting up, I sometimes had the problem that the system does not start properly at all. it just hangs in the bios. seems to have gotten better by using a USB hub inbetween.
* random USB disconnects and reconnects (only rarely)

dpiegdon, 2019-09-12:
Oh I forgot to note down the version. On the PCB there is a sticker with:

UHK60 V7.8
02578
2018/09/28

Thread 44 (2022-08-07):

Where can I find the files, for example in stl format, of the case for this keyboard?

dorcu, 2022-08-07:
Where can I find the files, for example in stl format, of the case for this keyboard?

mondalaci, 2022-08-07:
Please see https://ultimatehackingkeyboard.com/knowledgebase?q=stl

Closed 2022-08-07.

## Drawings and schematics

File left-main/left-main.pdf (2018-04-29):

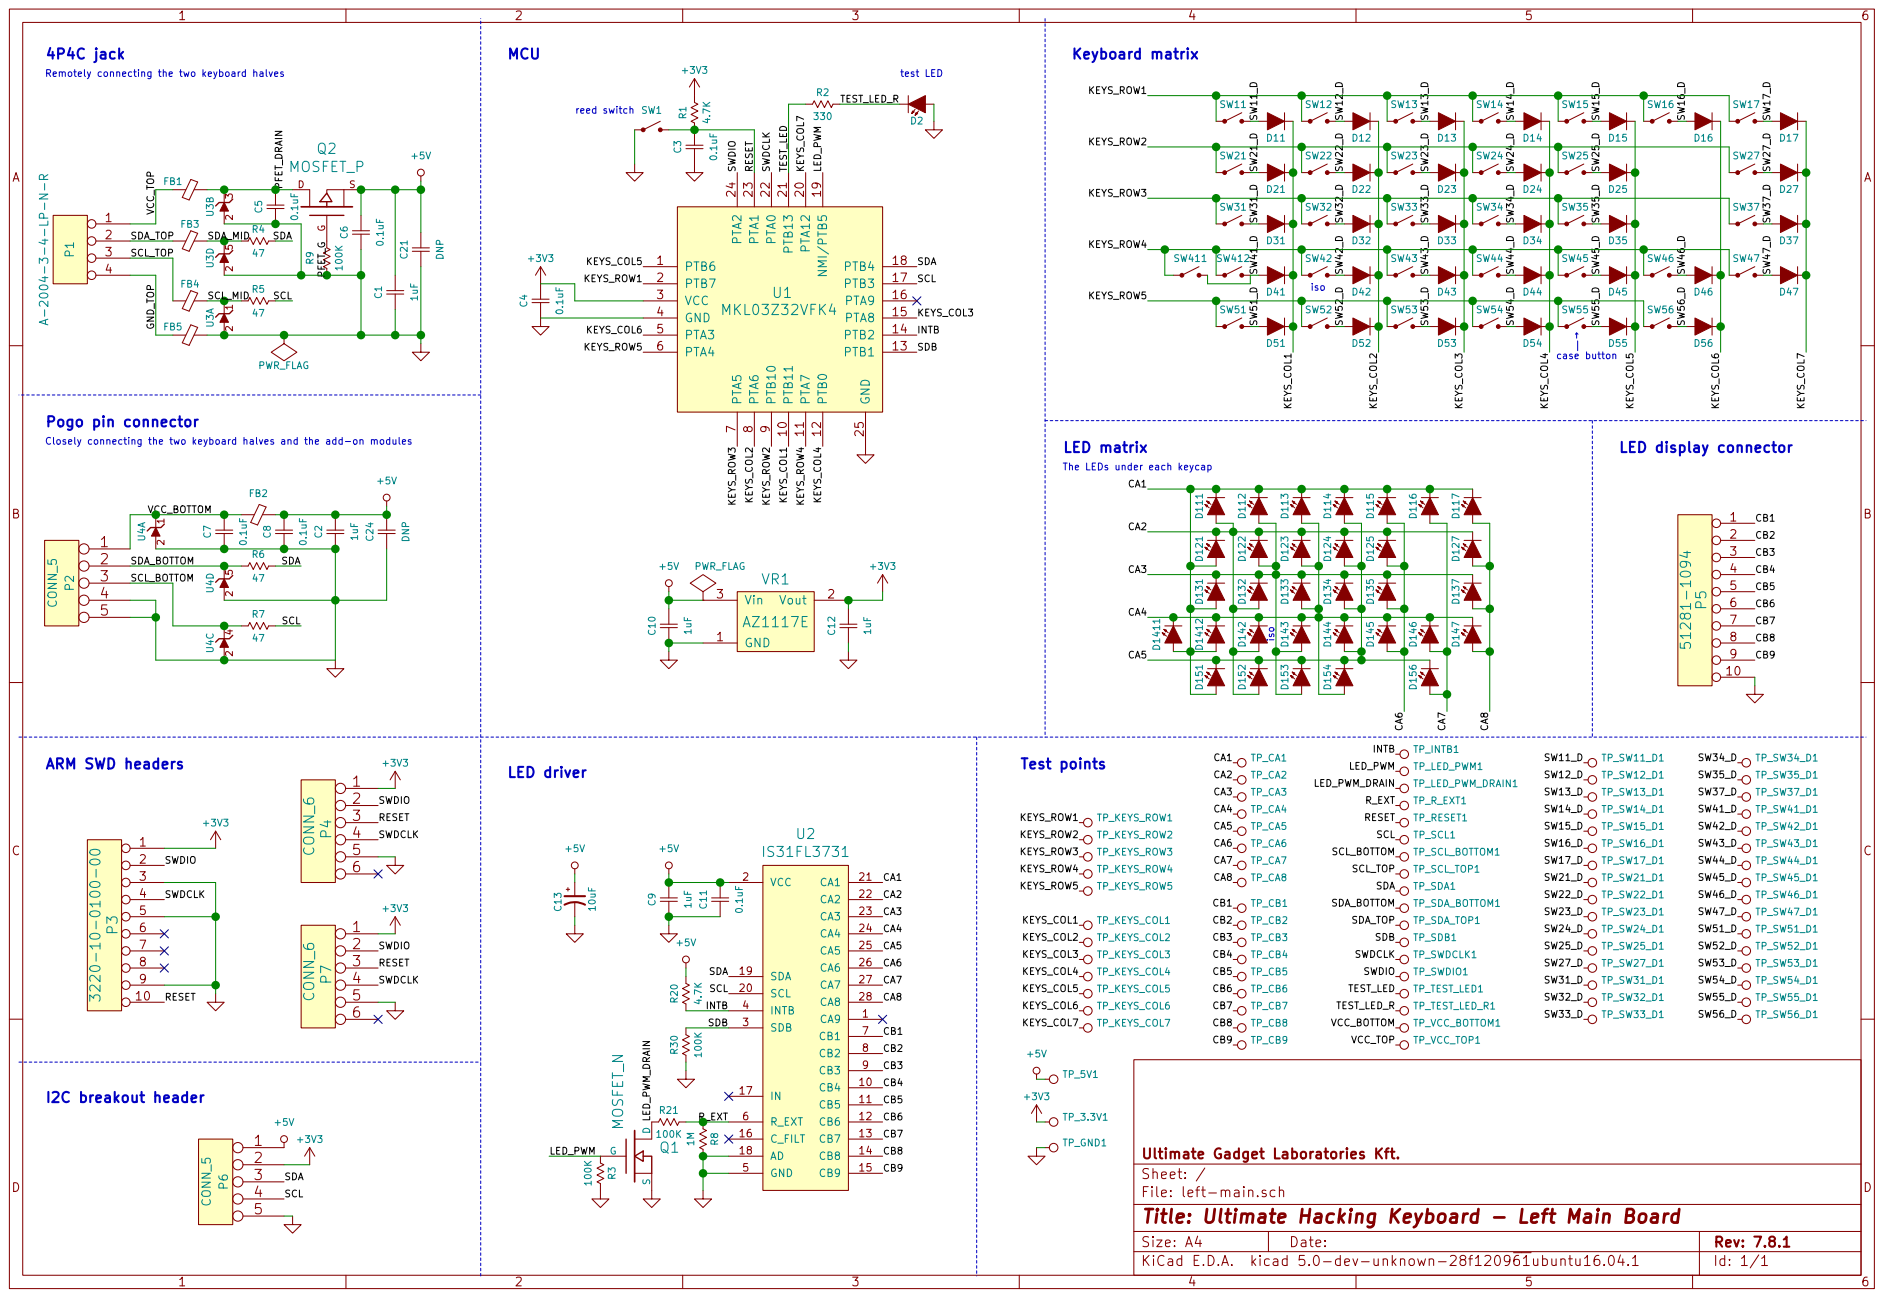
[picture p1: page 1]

The LEDs under each keycap MCU

File: left-main.sch Sheet: / Ultimate Gadget Laboratories Kft.

Id: 1/1 Title: Ultimate Hacking Keyboard - Left Main Board

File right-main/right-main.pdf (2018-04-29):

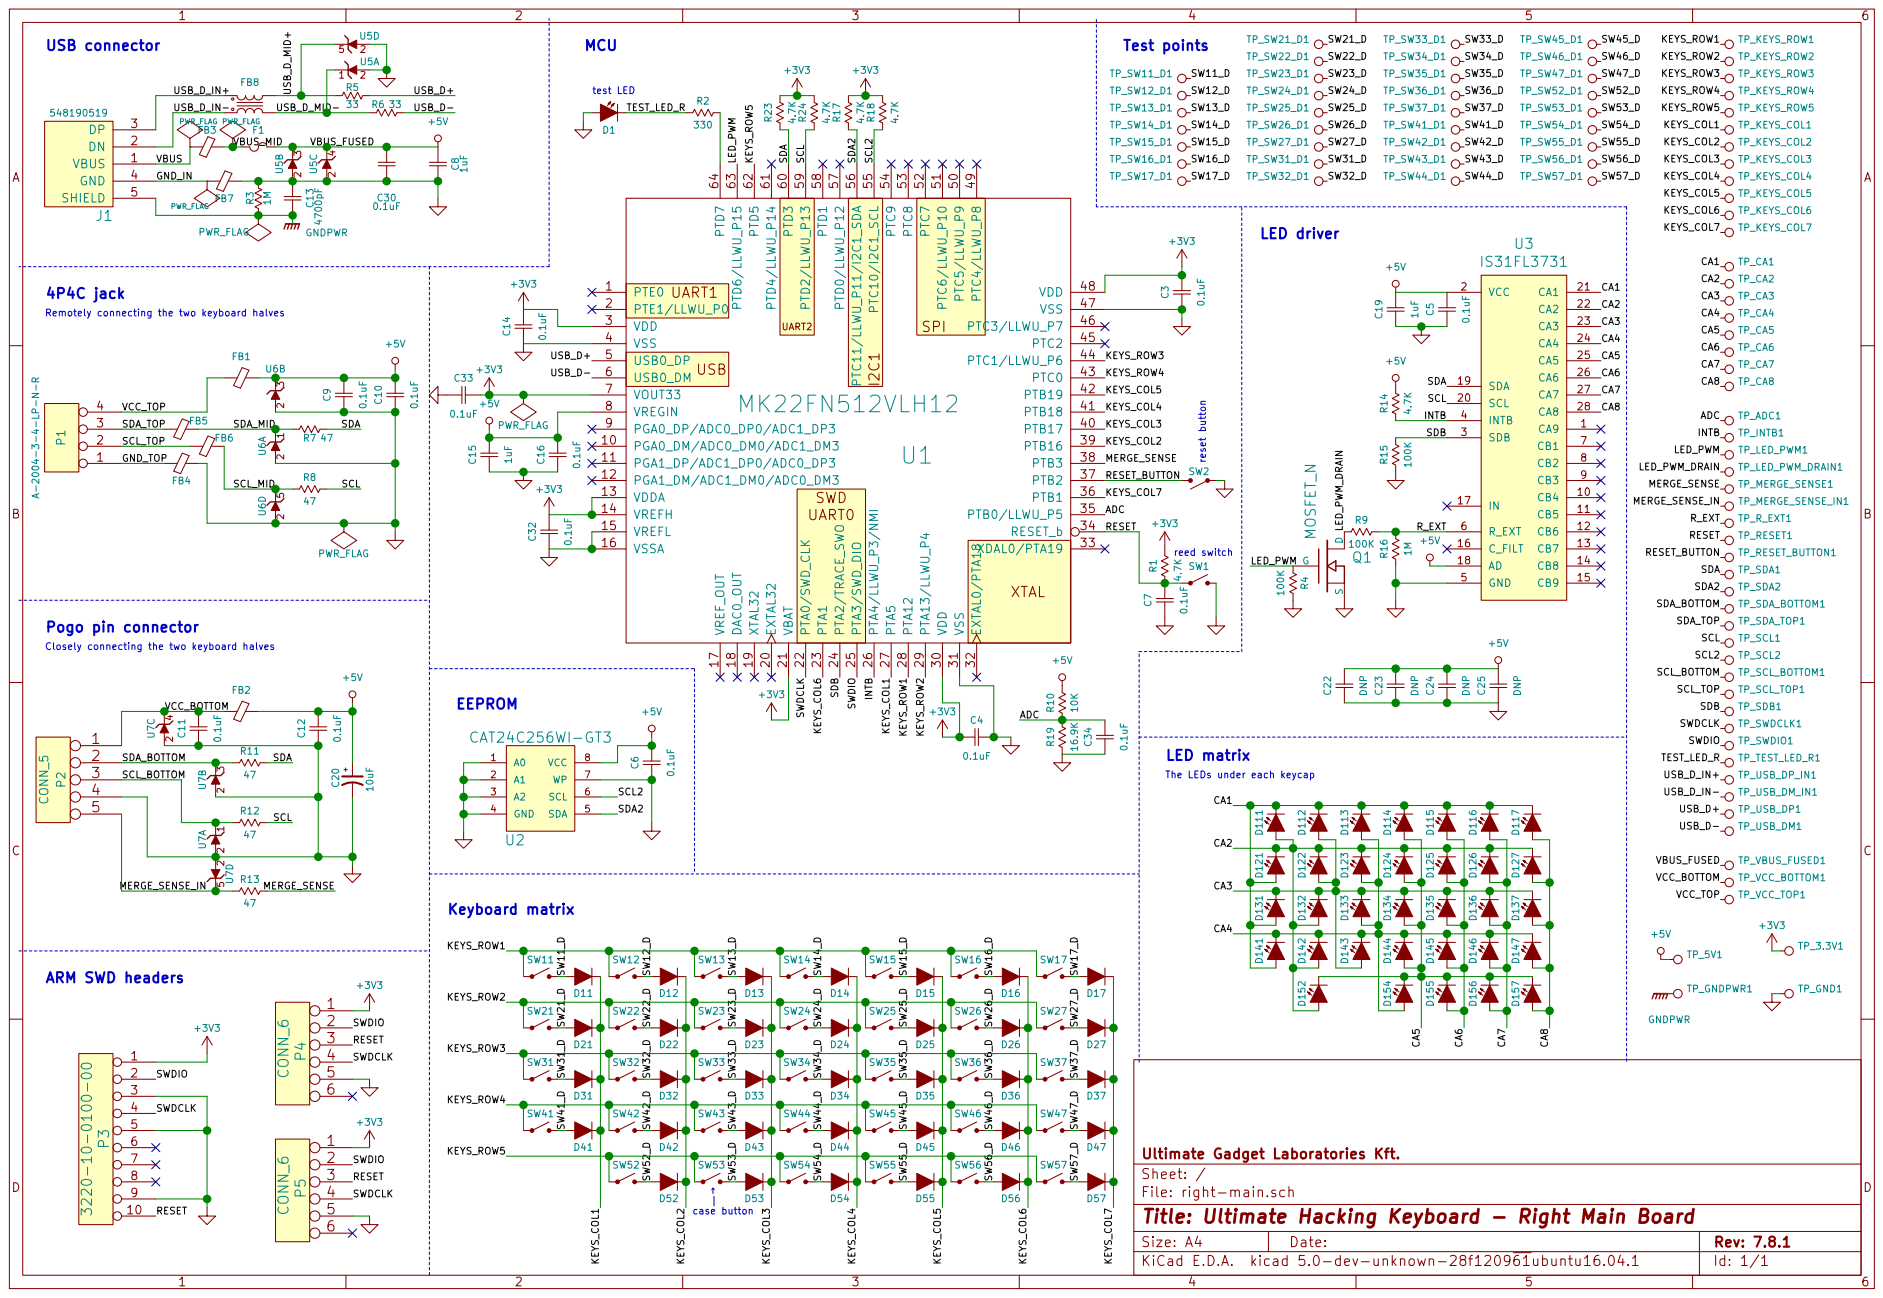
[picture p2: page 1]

reed switch reset button

Id: 1/1 Title: Ultimate Hacking Keyboard - Right Main Board

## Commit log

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2013-11-21 Add additional keepout areas and slightly correct PCB edge contour.
    [left-main.kicad_pcb]
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2013-11-21 Wire the LED matrix sink and source control lines towards the MCU.
    [left-main.kicad_pcb]
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2013-11-22 Move the MCU to its final location and wire some nearby components.
    [left-main.kicad_pcb]
2013-11-22 Wire the RX and TX of the RJ11 jack to the MCU.
    [left-main.kicad_pcb]
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2013-11-22 Place diodes at the same position relative to the MX switches wherever possible.
    [left-main.kicad_pcb]
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2013-11-23 Fully route TX, RX and VCC from the MCU to the spring connector.
    [left-main.kicad_pcb]
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2013-11-24 Add soft keepout area around the other side of the spring connector.
    [left-main.kicad_pcb]
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2013-11-26 Move the RJ11 jack, the USB connector and the bottommost microswitch into position.
    [right-main.kicad_pcb]
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2013-11-26 Replace the old board outline with the new.
    [right-main.kicad_pcb]
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2013-11-26 Lock every module which needs to be fixated.
    [display.kicad_pcb, left-main.kicad_pcb, right-main.kicad_pcb]
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2013-11-26 Move soft keepout area labels out of the way of modules to make them visible.
    [left-main.kicad_pcb]
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2013-11-27 Add missing keepout lines.
    [left-main.kicad_pcb]
2013-11-27 Resolve intersection on the keepout layer.
    [left-main.kicad_pcb]
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2013-11-29 Update hole modules to make them centered according to the center of the hole pad.
    [left-main.kicad_pcb, right-main.kicad_pcb]
2013-11-29 Route wires correctly by avoiding stubs.
    [left-main.kicad_pcb]
2013-11-30 Update net classes and default clearance.
    [right-main.kicad_pcb]
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2013-11-30 Fix the soft keepout area of boss 2 of 5.
    [right-main.kicad_pcb]
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2013-11-30 Fix the soft keepout area of boss 4 of 5
    [right-main.kicad_pcb]
2013-11-30 Fix the soft keepout area of boss 5 of 5.
    [right-main.kicad_pcb]
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2013-11-30 Fix reference designators and move them to visible positions.
    [right-main.kicad_pcb]
2013-11-30 Move the text marking the bottommost microswitch to reference the actual switch.
    [right-main.sch]
2013-12-01 Loosely place modules on the board.
    [right-main.kicad_pcb]
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2013-12-03 Correct USB connector pins.
    [right-main.kicad_pcb]
2013-12-03 Further progress with component placement and routing around the USB and RJ11 connectors.
    [right-main.kicad_pcb, right-main.sch]
2013-12-03 Use the new 1206 symbol with correct pin numbers and update netlist.
    [right-main.kicad_pcb, right-main.sch]
2013-12-03 Successfully escape from the labyrinth of the USB connector and RJ11 jack.
    [right-main.kicad_pcb]
2013-12-03 Finalize MCU orientation and position. Connect D+ and D-. Loosely place the EEPROM and the crystal.
    [right-main.kicad_pcb]
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2013-12-04 Route VCC all around the house with the exception of the ISP connector.
    [right-main.kicad_pcb]
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2013-12-04 Move the crystal out of the way of the soft keepout area.
    [right-main.kicad_pcb]
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2013-12-06 Slightly reposition the TPIC6C595 to keep it away from soft keepout areas. Connect DRAIN7 to KEYS_COL3. Make wires thicker around this region.
    [left-main.kicad_pcb, left-main.sch]
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2013-12-07 Better route VCC around the top of the board using monster sized tracks.
    [left-main.kicad_pcb]
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2013-12-07 Replace FFC connectors with their 18 pin variant.
    [display.kicad_pcb, left-main.kicad_pcb]
2013-12-07 Replace connector on the schematics, too.
    [left-main.kicad_pcb, left-main.sch]
2013-12-07 Make the schematics snazzy-looking by making better use of the available space and by drawing regions.
    [left-main.sch]
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2013-12-07 Fix the labels of the FFC connector and update netlist.
    [left-main.sch]
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2013-12-07 Make DRC errors disappear by properly routing KEYS_COL1 and KEYS_COL2.
    [left-main.kicad_pcb]
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2013-12-08 Move the actual hole of the hole modules into the center of the modules.
    [left-main.kicad_pcb]
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2013-12-08 Move the boards away from nearby texts because this way it's easier to wrap a ground fill around the boards without the text visually interfering.
    [display.kicad_pcb, left-main.kicad_pcb, right-main.kicad_pcb]
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2013-12-10 Add all the missing ground vias.
    [left-main.kicad_pcb]
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2013-12-10 Nuke DRC errors everywhere except in the vicinity of the FFC connector.
    [display.kicad_pcb]
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2013-12-10 Correctly position the reference designator of the FFC connector.
    [display.kicad_pcb]
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2013-12-11 Add comments for manufacturing tolerances.
    [left-main.kicad_pcb, right-main.kicad_pcb]
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2013-12-11 Get out of the way of the screw head soft keepout area.
    [right-main.kicad_pcb]
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2013-12-12 Shorten text and feature actual revision number.
    [display.kicad_pcb]
2013-12-12 Correct revision number and add it as the bottom silk screen.
    [connector.kicad_pcb]
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2013-12-12 Fix pad and via positioning.
    [connector.kicad_pcb]
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2013-12-13 Replace 2x3 pin header with dedicated ISP pin header module.
    [left-main.kicad_pcb, right-main.kicad_pcb]
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2013-12-13 Don't break out HWB and GND. DFU won't even be used to begin with, AVR109 will be used.
    [right-main.sch]
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2013-12-19 Replace atMega TQFP32 modules which contain a more reasonably drawn silkscreen.
    [left-main.kicad_pcb, right-main.kicad_pcb]
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2013-12-24 Set solder mask clearance to 4 mil.
    [connector.kicad_pcb, display.kicad_pcb, left-main.kicad_pcb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]
2013-12-24 Fix key labels.
    [right-main.kicad_pcb]
2013-12-24 Orient GNDPWR1 labels correctly.
    [left-main.kicad_pcb]
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2013-12-24 Resolve DRC errors.
    [left-main.kicad_pcb, right-main.kicad_pcb]
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2014-01-08 Reroute tracks to avoid the proximity of large drill holes.
    [right-main.kicad_pcb]
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2014-01-08 Swap row2 and row3 for more optimal routing.
    [right-main.kicad_pcb, right-main.sch]
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2014-01-09 Set correct default layer selections for gerber exports.
    [display.kicad_pcb, left-main.kicad_pcb, right-main.kicad_pcb]
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2014-01-10 Fix GND connection around C7.
    [right-main.kicad_pcb]
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2014-02-28 Resolve DRC issues. Optimize routing.
    [display.kicad_pcb]
2014-02-28 Fix COL8 on the schematic.
    [display.sch]
2014-02-28 Fix COL8 on the board.
    [display.kicad_pcb]
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2014-03-02 Fix edge contour.
    [right-main.kicad_pcb]
2014-03-05 Move the board edge and the FFC connector into their correct positions according to the CAD drawing.
    [display.kicad_pcb]
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2014-03-06 Fix track angle to be a multiple of 45 degrees.
    [display.kicad_pcb]
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2014-03-10 Tent ground vias by updating ground via modules of negative solder mask clearance.
    [display.kicad_pcb]
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2014-07-15 Remove the FET MUX. Chances are it won't be needed at all.
    [right-main.sch]
2014-07-15 Fix the pinout of the bottommost switches.
    [left-main.kicad_pcb, right-main.kicad_pcb]
2014-07-15 Fix the connections of the PNP transistor.
    [left-main.sch]
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2014-07-15 Exchange DISPLAY_ENABLE and KEYS_ROW3 in order for the SPI to work correctly.
    [left-main.sch]
2014-07-16 Wire the PNP correctly this time.
    [left-main.sch]
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2014-07-26 Replace the SPI EEPROM with an I2C EEPROM.
    [right-main.sch]
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2014-07-28 Reimport the corrected outline.
    [display.kicad_pcb]
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2014-07-31 Fix the position of front pads.
    [connector.kicad_pcb]
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2014-07-31 Fix the position of the pin contact line.
    [connector.kicad_pcb]
2014-07-31 Swap the front and pad pads of the first connection.
    [connector.kicad_pcb]
2014-07-31 Swap the top and bottom pads of the second connection.
    [connector.kicad_pcb]
2014-07-31 Swap the top and bottom pads of the third connection.
    [connector.kicad_pcb]
2014-07-31 Swap the top and bottom pads of the fourth connection.
    [connector.kicad_pcb]
2014-07-31 Swap the top and bottom pads of the fifth connection.
    [connector.kicad_pcb]
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2014-07-31 Fix via net names.
    [connector.kicad_pcb]
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2014-08-01 Fix edge contour near the vertical PCB.
    [right-main.kicad_pcb]
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2014-08-01 Fix the positions of ISP6 connectors.
    [left-main.kicad_pcb, right-main.kicad_pcb]
2014-08-02 Fix soft keepout area.
    [left-main.kicad_pcb]
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2014-08-03 Fix the orientation and move the labels of ISP6 headers.
    [left-main.kicad_pcb, right-main.kicad_pcb]
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2014-08-03 Fix outline near the RJ11 jack.
    [left-main.kicad_pcb]
2014-08-03 Now actually fix the outline near the RJ11 jack.
    [left-main.kicad_pcb]
2014-08-03 Fix edge contour near the RJ11 jack.
    [right-main.kicad_pcb]
2014-08-03 Now really fix edge contour near the RJ11 jack.
    [right-main.kicad_pcb]
2014-08-04 Fix the position of the RJ11 jacks.
    [left-main.kicad_pcb, right-main.kicad_pcb]
2014-08-07 Fix the position of the RJ11 jacks, hopefully for the last time.
    [left-main.kicad_pcb, right-main.kicad_pcb]
2014-08-07 Relabel a couple of caps. Add missing no connect symbols and junctions.
    [left-main.sch]
2014-08-07 Fix the orientation of the RJ11 connectors.
    [left-main.kicad_pcb, right-main.kicad_pcb]
2014-08-07 Resolve almost every DRC error. Rename some reference designators.
    [left-main.sch]
2014-08-08 Add PWR_FLAG symbols whenever needed to fix ERC issues.
    [left-main.sch]
2014-08-10 Rename some reference designators to avoid name conflicts.
    [right-main.sch]
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2014-08-10 Resolve ERC errors.
    [right-main.sch]
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2014-08-12 Loosely position new components.
    [left-main.kicad_pcb]
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2014-08-13 Fix reference designators. Remove unneeded modules.
    [right-main.kicad_pcb, right-main.sch]
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2014-08-15 Loosely move new parts to their final location. Label unlabelled nets that were confusing in the PCB editor.
    [left-main.kicad_pcb, left-main.sch, right-main.kicad_pcb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]
2014-08-15 Lock every component of fixed position.
    [right-main.kicad_pcb]
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2014-08-15 Fix net labels.
    [left-main.kicad_pcb, left-main.sch]
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2014-08-19 Fix the pin numbers of the PNP.
    [left-main.kicad_pcb]
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2014-08-20 Replace EEPROM footprint.
    [right-main.kicad_pcb]
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2014-08-22 Fully route every track except VCC and RESET.
    [left-main.kicad_pcb]
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2014-08-26 Replace the footprint of the ATmega32U4.
    [right-main.kicad_pcb]
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2014-08-27 Loosely arrange the rest of the tracks towards the MCU.
    [right-main.kicad_pcb, right-main.sch]
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2014-09-09 Fix tracks.
    [right-main.kicad_pcb]
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2014-09-11 Fix the wire that was off the board. Reposition some GND vias.
    [left-main.kicad_pcb]
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2014-09-13 Set solder mask clearance to 0.
    [connector.kicad_pcb, display.kicad_pcb, left-main.kicad_pcb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]
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2015-04-04 Set the package type of R10 and R16 and add them for the the board-to-board connector. Remove extra components now that the RJ11 jack doesn't have a shield.
    [right-main.kicad_pcb, right-main.sch]
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2015-04-05 Replace the ISP header with the standard, updated, non-staggered header.
    [left-main.kicad_pcb, right-main.kicad_pcb]
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2015-04-08 Fix the net of the keyboard matrix.
    [left-main.kicad_pcb, left-main.sch]
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2015-04-10 Replace CONN_5 with CONN_4 of the RJ11 jack because the new part doesn't have GND pins.
    [left-main.kicad_pcb, left-main.sch, right-main.kicad_pcb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]
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2015-04-11 Connect more nets near the MCU. Resolve DRC errors.
    [left-main.kicad_pcb]
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2015-04-17 Fix soft keepout areas.
    [right-main.kicad_pcb]
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2015-04-18 Fix DRC settings.
    [left-main.kicad_pcb, right-main.kicad_pcb]
2015-04-18 Resolve 1 DRC error and a number of others.
    [left-main.kicad_pcb]
2015-04-18 Resolve every DRC error.
    [left-main.kicad_pcb]
2015-04-18 Fix the labels of soft keepout areas.
    [left-main.kicad_pcb, right-main.kicad_pcb]
2015-04-18 Fix 2 DRC errors out of 3.
    [right-main.kicad_pcb]
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2015-04-22 Update clearances.
    [connector.kicad_pcb]
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2015-04-25 Fix project parameters.
    [connector.kicad_pcb]
2015-04-25 Reduce solder mask clearance to 0.
    [connector.kicad_pcb]
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2015-04-25 Update modules to fix their slik screen.
    [right-main.kicad_pcb]
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2015-04-25 Update components to fix the silk screen.
    [left-main.kicad_pcb]
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2015-04-26 Lock components of fixed positions.
    [left-main.kicad_pcb, right-main.kicad_pcb]
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2015-04-28 Fix component reference texts.
    [left-main.kicad_pcb, right-main.kicad_pcb]
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2015-04-29 Move away reference designator to not interfere with connector comments.
    [left-main.kicad_pcb]
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2015-05-21 Fix silk screen.
    [right-main.kicad_pcb]
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2015-12-13 Fixes issue #10, moves text
    [left-main.kicad_pcb]
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2016-01-22 Fix single pins.
    [connector.sch]
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2016-04-28 Replace Cherry MX modules with hybrid Cherry MX - Matias switch modules, and reverse them.
    [left-main.kicad_pcb, right-main.kicad_pcb]
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2016-04-30 Rip up tracks and remove most interfering components.
    [left-main.kicad_pcb]
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2016-05-02 Resolve DRC errors about nearby pads.
    [left-main.kicad_pcb]
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2016-05-04 Label correctly the ANSI left shift.
    [left-main.kicad_pcb]
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2016-05-05 Add special Cherry MX switch modules to avoid overlapping holes.
    [left-main.kicad_pcb]
2016-05-05 Use special MX LED modules to avoid overlapping pads and holes around the ISO key.
    [left-main.kicad_pcb]
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2016-05-14 Lock the positions of several modules to avoid soft keepout areas.
    [left-main.kicad_pcb, right-main.kicad_pcb]
2016-05-15 Replace 18 pin FFC connectors with 10 pin FFC connectors.
    [display.kicad_pcb, left-main.kicad_pcb]
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2016-05-26 Add QFN-24 module for the MCU and set the clearance in the design rules to 7 mil.
    [left-main.kicad_pcb]
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2016-05-27 Replace the 18 pin connector with a 10 pin connector and wire it to the LED driver.
    [left-main.sch]
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2016-05-27 Replace the AVR ISP headers with ARM SWD headers.
    [left-main.sch, right-main.sch]
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2016-05-27 Draw lines between the distinct schematic regions. Fix phrasing in some sentences.
    [left-main.sch, right-main.sch]
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2016-05-28 Resolve most ERC errors.
    [left-main.sch]
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2016-05-28 Resolve all ERC issues.
    [left-main.sch]
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2016-05-30 Fix USB circuitry and the circuitry around the I2C connectors of the right keyboar half.
    [left-main.sch, right-main.sch]
2016-05-30 Put text on the back of the PCB because it won't be seen on the front due to being covered by the display module.
    [display.kicad_pcb]
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2016-06-01 Fix conflicting P4 reference designators. Change the reference designator of the reed switch to SW1.
    [left-main.sch]
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2016-06-03 Add a 0.1uF capacitor between GND and RESET which is highly recommended to prevent noisy spikes resetting the MCU.
    [left-main.sch, right-main.sch]
2016-06-04 Remove D153 as the bottommost button has no LED. Put missing components onto the board.
    [right-main.kicad_pcb, right-main.sch]
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2016-06-04 Move the MCU and LED driver to their final position. Replace the MCU footprint with the slighly modified 7 mil tolerant footprint.
    [left-main.kicad_pcb, left-main.sch]
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2016-06-09 Replace individual TVS diodes with TVS arrays.
    [right-main.kicad_pcb, right-main.sch]
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2016-06-16 Fix 2 junction points and a drawing separator line.
    [right-main.sch]
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2016-06-16 Fix separator line position.
    [right-main.sch]
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2016-06-16 Fix junctions.
    [right-main.sch]
2016-06-16 Fix graphics separator lines.
    [left-main.sch]
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2016-06-20 Pull up RESET, just to be sure.
    [left-main.sch, right-main.sch]
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2016-06-21 Connect AD to VCC instead of SCL to surely not interfere with I2C.
    [right-main.sch]
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2016-06-27 Make the tracks between R4/R5 and the MCU constant width to improve overshoot and ringing.
    [left-main.kicad_pcb]
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2016-06-29 Make way for SPI, USB and 5V tracks via a shorter path.
    [right-main.kicad_pcb, right-main.sch]
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2016-06-30 Place the LED driver into its final position. Route the tracks of the LED matrix more tightly to leave more space for 5V, SDA, and SCL.
    [right-main.kicad_pcb, right-main.sch]
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2016-07-02 Replace the 0.1" SWD headers with 0.05" headers.
    [left-main.kicad_pcb, left-main.sch, right-main.kicad_pcb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]
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2016-07-05 Add missing no connect symbols.
    [right-main.sch]
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2016-07-07 Resolve ERC issue. Remove comment regarding board and silk screen color.
    [display.kicad_pcb, display.sch]
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2016-07-15 Fix insert attributes.
    [right-main.kicad_pcb]
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2016-07-16 Revert board position and redo the last few steps while keeping everything on the grid: Update board position to leave equal distances around the edges. Don't insert the components of the test LEDs. 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
    [right-main.kicad_pcb]
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2016-07-27 Fix dimension lines.
    [connectors.kicad_pcb]
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2016-08-05 Replace the 4 pin I2C breakout header with a 5 pin header featuring both 3.3V and 5V.
    [left-main.kicad_pcb, left-main.sch]
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2016-08-06 Swap SDA and SCL so standard telephone cords should be compatible with the UHK.
    [right-main.kicad_pcb, right-main.sch]
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2016-08-07 Fix silk screen for SDA and SCL.
    [right-main.kicad_pcb]
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2016-08-26 Fix the pinout of the voltage regulator and reroute relevant tracks.
    [left-main.kicad_pcb]
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2016-09-13 Replace FFC_Connector_SFV10R-4STE1HLF with FFC_Connector_SFV10R-2STE1HLF.
    [display.kicad_pcb, display.sch, left-main.kicad_pcb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]
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2016-10-28 Reverse the diodes of keyboard matrices.
    [left-main.kicad_pcb, left-main.sch, right-main.kicad_pcb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]
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2016-10-28 Invert the pads of the LEDs because they were in reverse. Slightly reroute some tracks to comply with DRC.
    [left-main.kicad_pcb, right-main.kicad_pcb]
2016-10-28 Replace the now obsoleted PTS525SM10SMTRLFS switch with the EVQPLMA15.
    [right-main.kicad_pcb, right-main.sch]
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2016-11-15 Use left pin only or right pin only switches where the stabilizer pin interferes with the edge of the PCB.
    [left-main.kicad_pcb, left-main.sch, right-main.kicad_pcb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]
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2016-11-22 Replace C1 and C2 0805 packages with 1205.
    [right-main.kicad_pcb, right-main.sch]
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2016-11-23 Add a 100nF cap, a 100uF cap, and a ferrite bead near the USB connector to reduce electrical noise.
    [right-main.kicad_pcb, right-main.sch]
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2016-11-26 Fix the values of test points, add missing ones, and reposition some.
    [left-main.kicad_pcb, left-main.sch, right-main.kicad_pcb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]
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2016-11-28 Set the clearance from 7 mil to 8 mil and tweak the board to comply.
    [left-main.kicad_pcb]
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2016-11-29 Make the board compliant to 8 mil clearance.
    [right-main.kicad_pcb]
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2016-11-29 Fix the clearance of FID1.
    [display.kicad_pcb]
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2016-11-30 Replace 22/38 mil vias with 20/38 mil vias.
    [right-main.kicad_pcb]
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2016-11-30 Replace 22/38 mil vias with 20/38 mil vias. Update 2x5 header.
    [left-main.kicad_pcb]
2016-11-30 Update QFN24 component to allow for 8 mil clearance.
    [left-main.kicad_pcb]
2016-11-30 Reinforce the connection of VCC tracks with multiple vias.
    [left-main.kicad_pcb, right-main.kicad_pcb]
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2016-12-04 Remove old merge script because gerbv doesn't work with oval holes and hardly supports Gerber X2.
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2016-12-15 Fix the values of 0.1uF 1206 caps to 100uF.
    [right-main.kicad_pcb, right-main.sch]
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2016-12-28 Switch ARM header to its space optimized version and move it downwards in order to not interfere with the plastic case mechanically, not even when hand-soldered the worst way possible.
    [left-main.kicad_pcb, right-main.kicad_pcb]
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2016-12-28 Replace the 0955012441 4P4C jack with A-2004-3-4-LP-N-R so that the clip of the 4P4C plug is accessible now.
    [left-main.kicad_pcb, left-main.sch, right-main.kicad_pcb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]
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2017-01-15 Use 4.7K resistor instead of 10K for pulling up RESET.
    [left-main.sch]
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2017-01-25 Fix routing.
    [display.kicad_pcb]
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2017-01-25 Replace the left side FFC connector, too.
    [left-main.kicad_pcb, left-main.sch]
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2017-01-29 Use 2 vias per pad. Fixes #36.
    [connectors.kicad_pcb]
2017-01-29 Add reverse voltage protection circut. The components have yet to be routed.
    [left-main.kicad_pcb, left-main.sch]
2017-01-30 Route reverse protection. Fixes #35.
    [left-main.kicad_pcb, left-main.sch]
2017-01-31 Replace SC74A TVS arrays with SC74. Closes #31.
    [left-main.kicad_pcb, right-main.kicad_pcb]
2017-01-31 Begin rigth side redesign:
    -Fix issue #33
    -Remove all VIA which defined as PAD
    -Change desing rules
    -Rename diff. pair nets
    -Fix TVS array footprint in schematic
    [right-main.kicad_pcb, right-main.sch]
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2017-02-02 *fix net names in schematic editor
    [right-main.sch]
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2017-02-06 Fix netnames on testpoints. Change connections on TVS.
    [right-main.sch]
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2017-02-16 DRC and routing fixes.
    [right-main.kicad_pcb]
2017-02-18 Fix DRC errors and align designators on silkscreen layer.
    [right-main.kicad_pcb]
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2017-02-19 Some fixes according to "UHK PCB validation check" document.
    [right-main.kicad_pcb, right-main.sch]
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2017-02-20 Fix last DRC error.
    [right-main.kicad_pcb]
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2017-02-20 Update open HW logo and increase clearance between rib and components.
    [right-main.kicad_pcb]
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2017-02-21 Fix keepout collision (USB EMI parts).
    [right-main.kicad_pcb]
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2017-03-08 Redesign the pitch and space of the female vertical PCB inner pads according to the newly available space.
    [connectors.kicad_pcb]
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2017-03-23 Change schematic near USB and I2C connectors. (ESD/EMI)
    [right-main.sch]
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2017-03-25 Reordering parts according to ESD/EMI requirements.
    [right-main.kicad_pcb]
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2017-03-26 Issue #37. Change MKL03Z8VFK4 to MKL03Z32VFK4 and TVS footprint.
    [left-main.sch]
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2017-03-28 Fix bead connection. Rotate SW37.
    [left-main.sch]
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2017-03-28 End of day #1. (Redesign of left-main board.)
    [left-main.kicad_pcb]
2017-03-29 End of day #2. (Redesign of left-main board.)
    [left-main.kicad_pcb]
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2017-04-03 End of day #3. (Redesign of left-main board.)
    [left-main.kicad_pcb]
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2017-04-04 Fix routing on right-main board. (updated contour)
    [right-main.kicad_pcb]
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2017-04-05 Extract SWDIO, SWDCLK, RESET, 3V3, VCC, GND, SDA and SCL via breakout tabs.
    [left-main.kicad_pcb]
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2017-04-05 Extract the SWDIO, SWDCLK, RESET, 3.3V of the right board via breakout tabs.
    [right-main.kicad_pcb]
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2017-04-06 Resolve DRC errors that surface upon panelization.
    [right-main.kicad_pcb]
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2017-04-07 Resolve DRC error which surfaces when regenerating the panel.
    [left-main.kicad_pcb]
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2017-04-07 Fix reference designators.
    [left-main.kicad_pcb, right-main.kicad_pcb]
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2017-04-09 Resolve ERC warnings.
    [right-main.sch]
2017-04-09 Resolve ERC error.
    [right-main.sch]
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2017-05-05 Move GND via outside of the GND pad of C23 to avoid tombstoning.
    [right-main.kicad_pcb]
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2017-05-18 Put versioning information on the silk screen because this way it won't affect the copper layer if it gets changed, possibly affecting EMI compliance.
    [left-main.kicad_pcb, right-main.kicad_pcb]
2017-05-18 Bump version number from 7.2 to 7.3.0. Patch version signifies silk screen changes. Remove issue dates.
    [display.kicad_pcb, left-main.kicad_pcb, right-main.kicad_pcb]
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2017-05-18 Replace 24K with 10K and 36K with 16.9K.
    [right-main.kicad_pcb, right-main.sch]
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2017-05-26 Replace the 2.6 mm diameter holes to 2.4 mm on the top of the left and right boards.
    [left-main.kicad_pcb, right-main.kicad_pcb]
2017-05-26 Fix the position of the reset switch according to CAD data.
    [right-main.kicad_pcb]
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2017-05-28 Reposition the Tag-Connect header to make it not interfere with the top keepout areas of keycap stabilizers.
    [right-main.kicad_pcb]
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2017-06-03 Replace 10uF caps with 1uF.
    [left-main.kicad_pcb, left-main.sch, right-main.kicad_pcb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]
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2017-07-23 Make SW412 virtual which will display correct component quantities in the generated BOM.
    [left-main.kicad_pcb]
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2017-12-07 Add RESET labels for ARM SWD header pins. Update the silk screen of 4P4C jacks.
    [left-main.kicad_pcb, right-main.kicad_pcb]
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2017-12-07 Replace rescued 3.3V and GND symbols to their non-rescued counterparts.
    [left-main.sch, right-main.sch]
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2018-04-29 Fix the symbol library table of the left board.
2018-04-29 Fix the symbol library table of the right board.
2018-04-29 Fix the symbol library table of the connector.
2018-04-29 Fix the symbol library table of the connector. (Previously I fixed the symbol library table of the display.)
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2021-11-08 Update README.md
    https://forum.kicad.info/t/warning-avoid-all-links-to-kicad-pcb-org-use-kicad-org/31521
